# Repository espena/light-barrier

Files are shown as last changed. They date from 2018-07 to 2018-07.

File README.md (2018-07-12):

# Light barrier
Garage door light barrier. KiCad project with schematics and PCB layout. This project is shared under GNU general public license version 3, and is provided "as is", with no warranties what so ever. Use this material completely at your own risk.

## Transmitter circuit

| Component ID  | Type | Description | Value  |
| --- |:---|:---| ---:|
|  C1 | Capacitor | Radial electrolytic, 10V | 1000µF |
|  C2 | Capacitor | Monolithic Ceramic Chip |  470pF |
|  C3 | Capacitor | Monolithic Ceramic Chip |  100nF |
|  C4 | Capacitor | Monolithic Ceramic Chip |  100nF |
|  C5 | Capacitor | Monolithic Ceramic Chip |  100nF |
|  D1 | Diode | 1N4001, 50V | -  |
|  D2 | LED | Green, 5mm | -  |
|  D3 | IR-LED | TSAL 6100 | -  |
|  J1 | Terminal block | KF128 2-pin, 5 mm pitch | -  |
| JP1 | Jumper | 1x2 pin header with jumper | -  |
|  Q1 | Transistor | BC338 NPN BJT | -  |
|  R1 | Resistor | Metal film, 1% tolerance | 1kΩ |
|  R2 | Resistor | Metal film, 1% tolerance | 24kΩ |
|  R3 | Resistor | Metal film, 1% tolerance |  120kΩ |
|  R4 | Resistor | Metal film, 1% tolerance | 22kΩ |
|  R5 | Resistor | Metal film, 1% tolerance |  680kΩ |
|  R6 | Resistor | Metal film, 1% tolerance | 10kΩ |
|  R7 | Resistor | Metal film, 1% tolerance |  100kΩ |
|  R8 | Resistor | Metal film, 1% tolerance | 10Ω  |
| RV1 | Potentiometer  | Cermet 25-turn 3296W-1 | 10kΩ |
|  U1 | IC | TLC555 timer circuit | -  |
|  U2 | IC | TLC555 timer circuit | -  |

PCB layout for the transmitter is shared via
[OSH Park](https://oshpark.com/shared_projects/Knkobcg6)

## Receiver circuit

| Component ID  | Type | Description | Value  |
| --- |:---|:---| ---:|
|  C1 | Capacitor | Radial electrolytic | 47µF |
|  C2 | Capacitor | Monolithic Ceramic Chip |  100nF |
|  C3 | Capacitor | Radial electrolytic | 10µF |
|  C4 | Capacitor | Monolithic Ceramic Chip |  100nF |
|  C5 | Capacitor | Monolithic Ceramic Chip |  100nF |
|  C6 | Capacitor | Monolithic Ceramic Chip |  100nF |
|  C7 | Capacitor | Radial electrolytic, 10V | 1000µF |
|  D1 | Diode | 1N4001, 50V | -  |
|  D2 | Diode | 1N4001, 50V | -  |
|  D3 | LED | Red, 5mm | -  |
|  D4 | Diode | 1N4001, 50V | -  |
|  J1 | Terminal block | KF128 2-pin, 5 mm pitch | -  |
|  Q1 | Transistor | BC557 PNP BJT | -  |
|  Q2 | Transistor | TIP120 darlington | -  |
|  R1 | Resistor | Metal film, 1% tolerance |  6,2kΩ |
|  R2 | Resistor | Metal film, 1% tolerance | 100Ω |
|  R3 | Resistor | Metal film, 1% tolerance |  100kΩ |
|  R4 | Resistor | Metal film, 1% tolerance |  100kΩ |
|  R5 | Resistor | Metal film, 1% tolerance |  6,8kΩ |
|  R6 | Resistor | Metal film, 1% tolerance | 1kΩ |
| RV1 | Potentiometer  | Cermet 25-turn 3296W-1 |  100kΩ |
| RV2 | Potentiometer  | Cermet 25-turn 3296W-1 |  100kΩ |
|  U1 | IC | VS1838 IR receiver | -  |
|  U2 | IC | TLC555 timer circuit | -  |
|  U3 | IC | TLC555 timer circuit | -  |

PCB layout for the receiver is shared via
[OSH Park](https://oshpark.com/shared_projects/EA8wav7z)

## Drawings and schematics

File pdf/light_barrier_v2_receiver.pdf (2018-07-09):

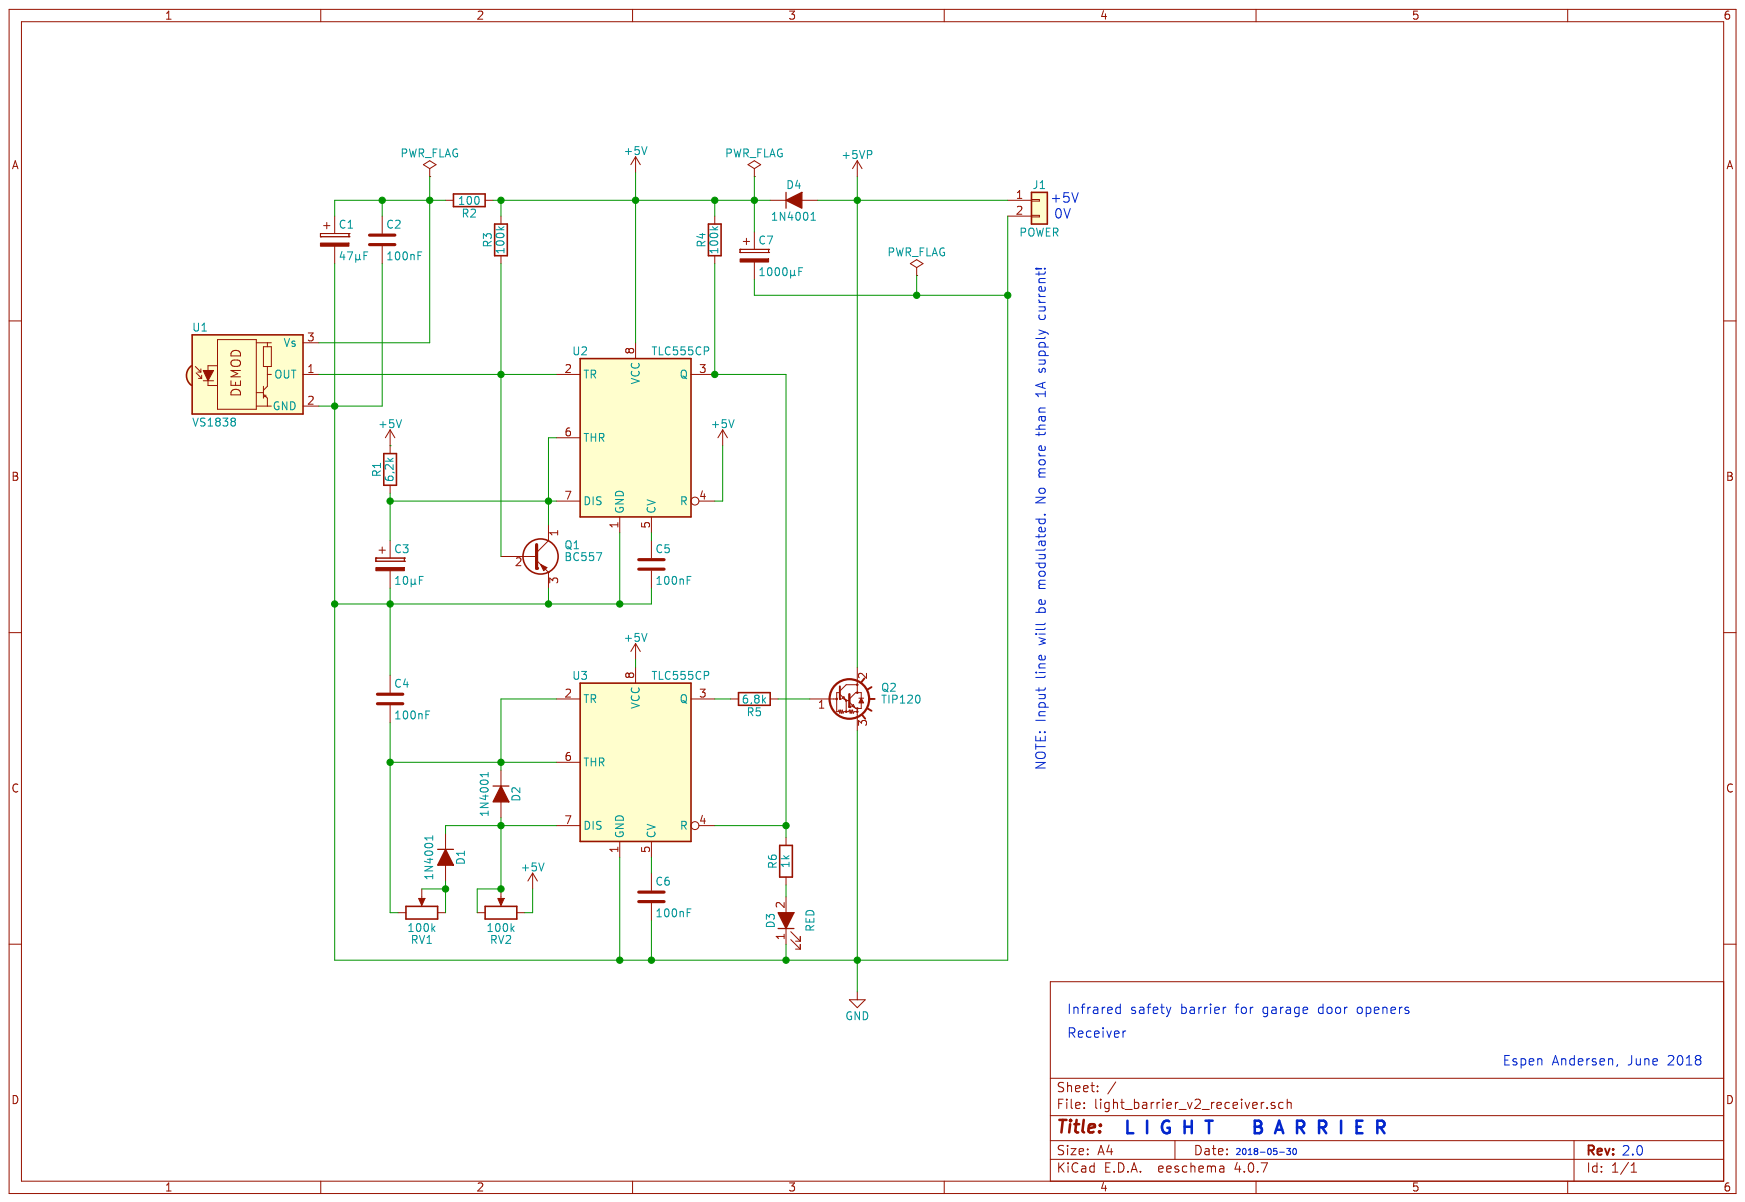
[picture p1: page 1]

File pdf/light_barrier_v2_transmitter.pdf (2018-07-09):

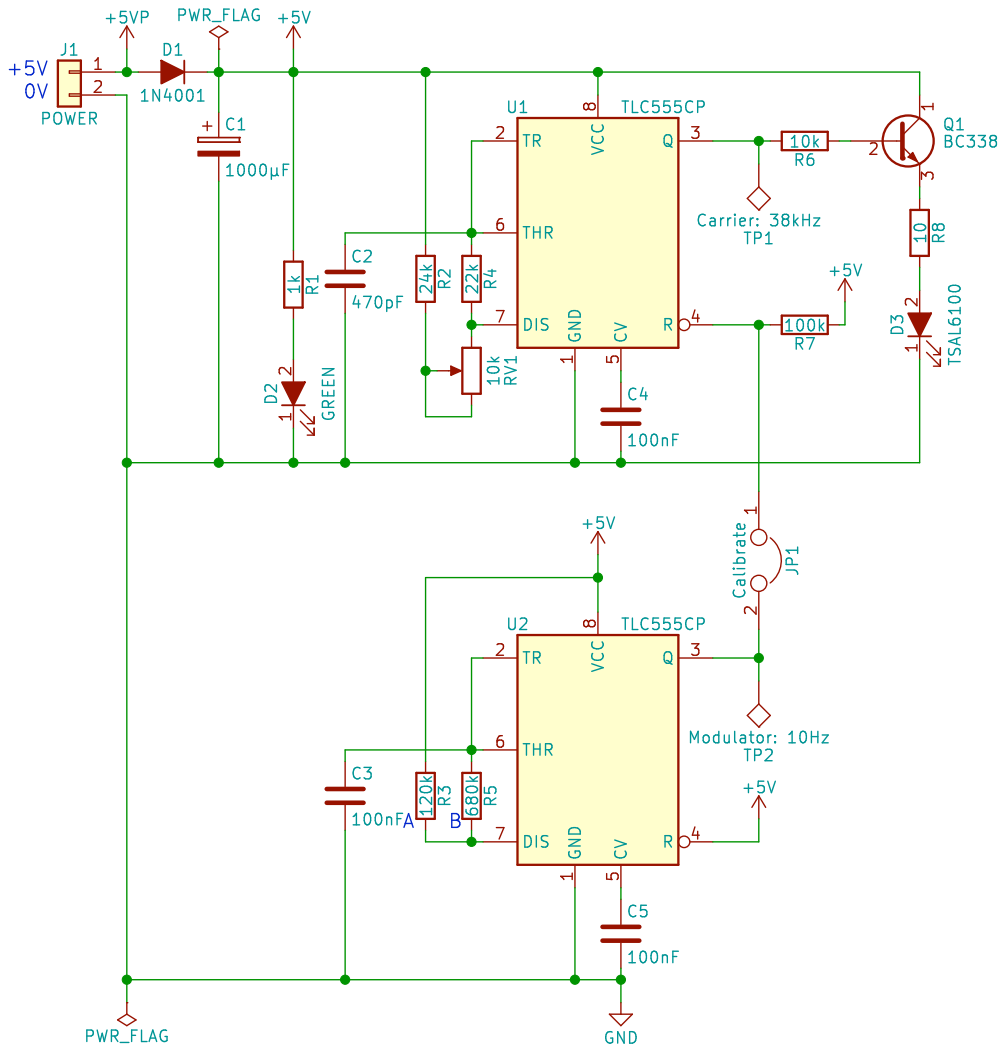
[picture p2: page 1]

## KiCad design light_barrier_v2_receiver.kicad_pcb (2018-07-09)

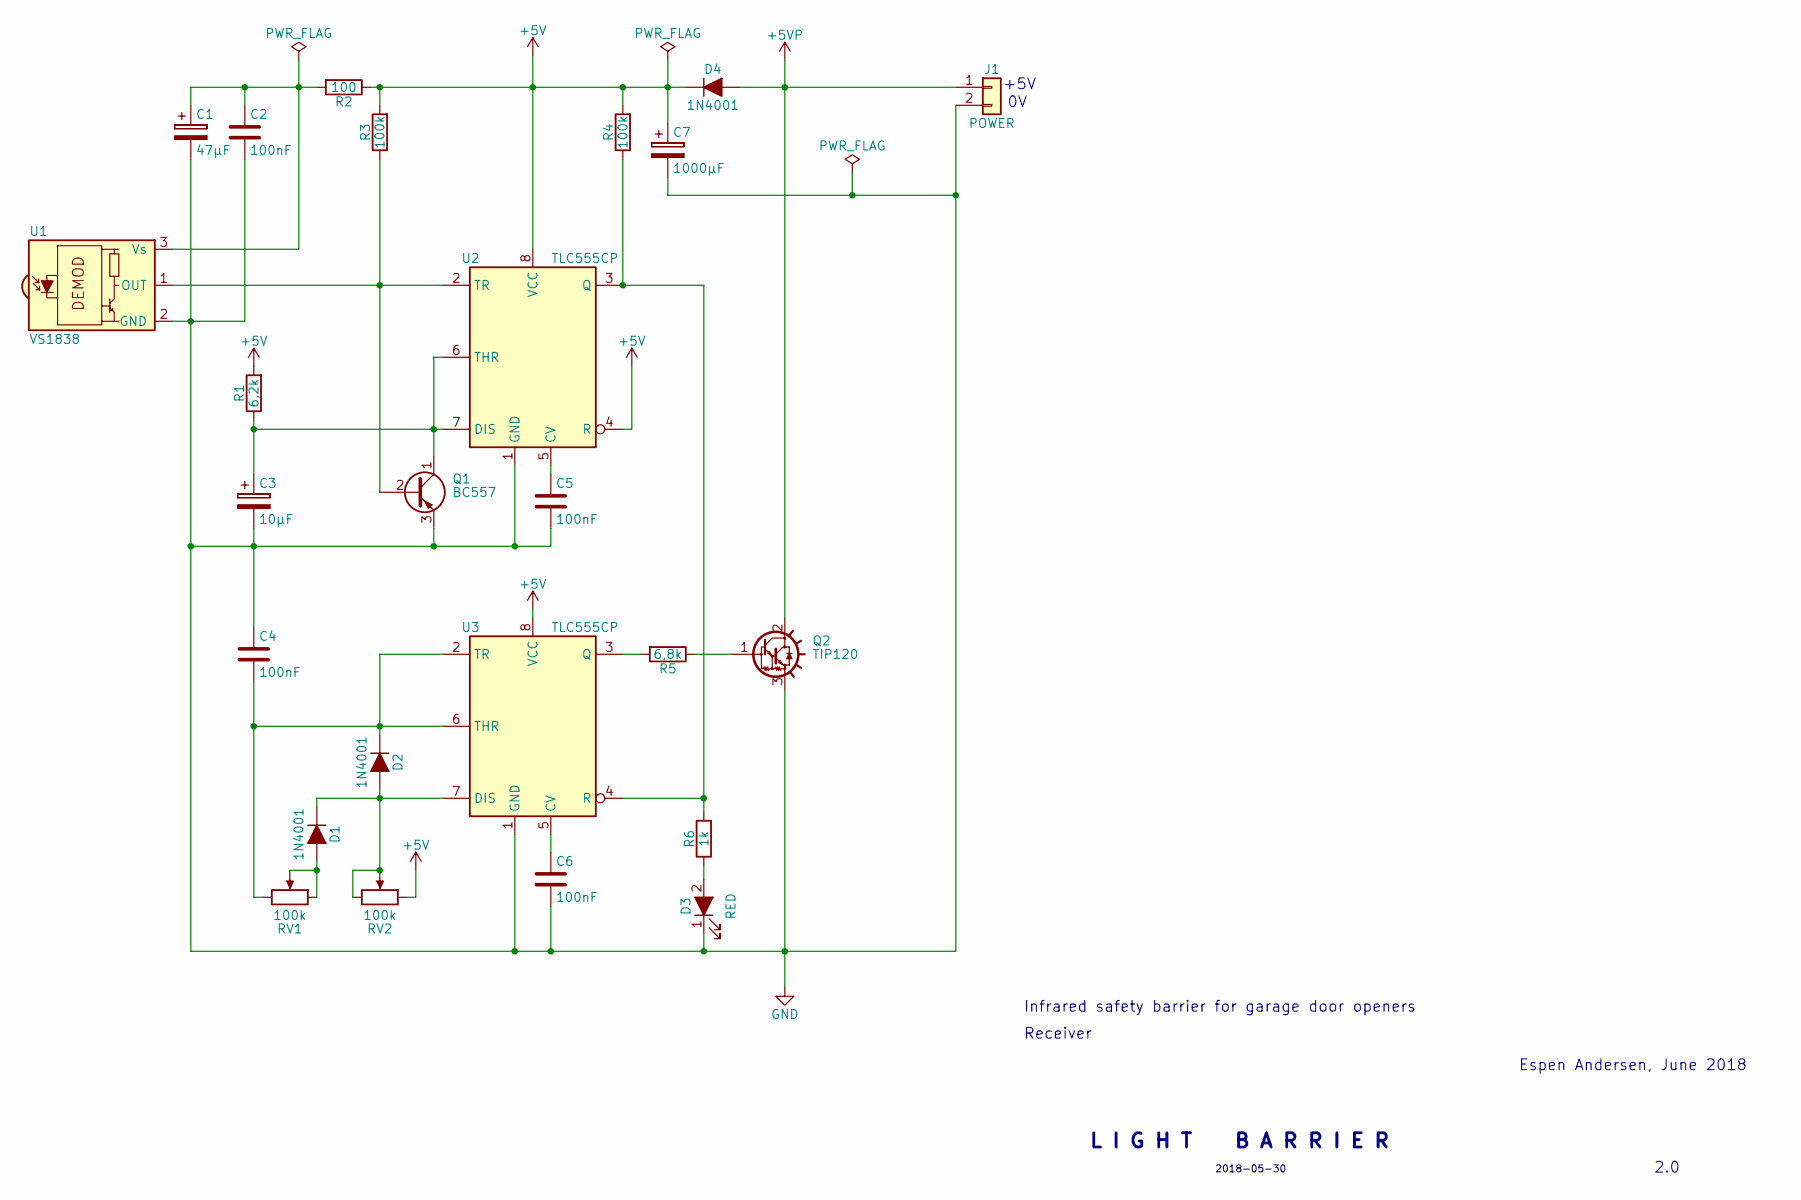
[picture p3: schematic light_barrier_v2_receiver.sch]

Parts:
C1: 47µF; CP_Radial_D4.0mm_P2.00mm
C2, C4, C5, C6: 100nF; C_Disc_D4.3mm_W1.9mm_P5.00mm
C3: 10µF; CP_Radial_D4.0mm_P2.00mm
C7: 1000µF; CP_Radial_D12.5mm_P5.00mm
D1, D2: 1N4001; D_DO-41_SOD81_P2.54mm_Vertical_KathodeUp
D3: RED; LED_D5.0mm
D4: 1N4001; D_DO-41_SOD81_P7.62mm_Horizontal
J1: POWER; TerminalBlock_Phoenix_PT-3.5mm_2pol
Q1: BC557; TO-92_Molded_Narrow_Oval
Q2: TIP120; TO-220-3_Vertical
R1: 6,2k; R_Axial_DIN0207_L6.3mm_D2.5mm_P2.54mm_Vertical
R2: 100; R_Axial_DIN0207_L6.3mm_D2.5mm_P7.62mm_Horizontal
R3, R4: 100k; R_Axial_DIN0207_L6.3mm_D2.5mm_P2.54mm_Vertical
R5: 6,8k; R_Axial_DIN0207_L6.3mm_D2.5mm_P2.54mm_Vertical
R6: 1k; R_Axial_DIN0207_L6.3mm_D2.5mm_P2.54mm_Vertical
RV1, RV2: 100k; Potentiometer_Trimmer_Bourns_3296W
U1: VS1838; IRReceiver_Vishay_MINICAST-3pin
U2, U3: TLC555CP; DIP-8_W7.62mm_LongPads

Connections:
+5V: C7.1, D4.1 (K), R1.2, R2.1, R3.2, R4.2, RV2.1, U2.4 (R), U2.8 (VCC), U3.8 (VCC)
+5VP: D4.2 (A), J1.1, Q2.2 (C)
GND: C1.2, C2.2, C3.2, C4.1, C5.2, C6.2, C7.2, D3.1 (K), J1.2, Q1.3 (E), Q2.3 (E), U1.2 (GND), U2.1 (GND), U3.1 (GND)
unnamed: C1.1, C2.1, R2.2, U1.3 (Vs)
unnamed: C3.1, Q1.1 (C), R1.1, U2.6 (THR), U2.7 (DIS)
unnamed: C4.2, D2.1 (K), RV1.3, U3.2 (TR), U3.6 (THR)
unnamed: C5.1, U2.5 (CV)
unnamed: C6.1, U3.5 (CV)
unnamed: D1.1 (K), D2.2 (A), RV2.2, RV2.3, U3.7 (DIS)
unnamed: D1.2 (A), RV1.1, RV1.2
unnamed: D3.2 (A), R6.1
unnamed: Q1.2 (B), R3.1, U1.1 (OUT), U2.2 (TR)
unnamed: Q2.1 (B), R5.1
unnamed: R4.1, R6.2, U2.3 (Q), U3.4 (R)
unnamed: R5.2, U3.3 (Q)

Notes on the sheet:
L I G H T B A R R I E R
Espen Andersen, June 2018
2018-05-30
2.0
Infrared safety barrier for garage door openers
+5V
Receiver

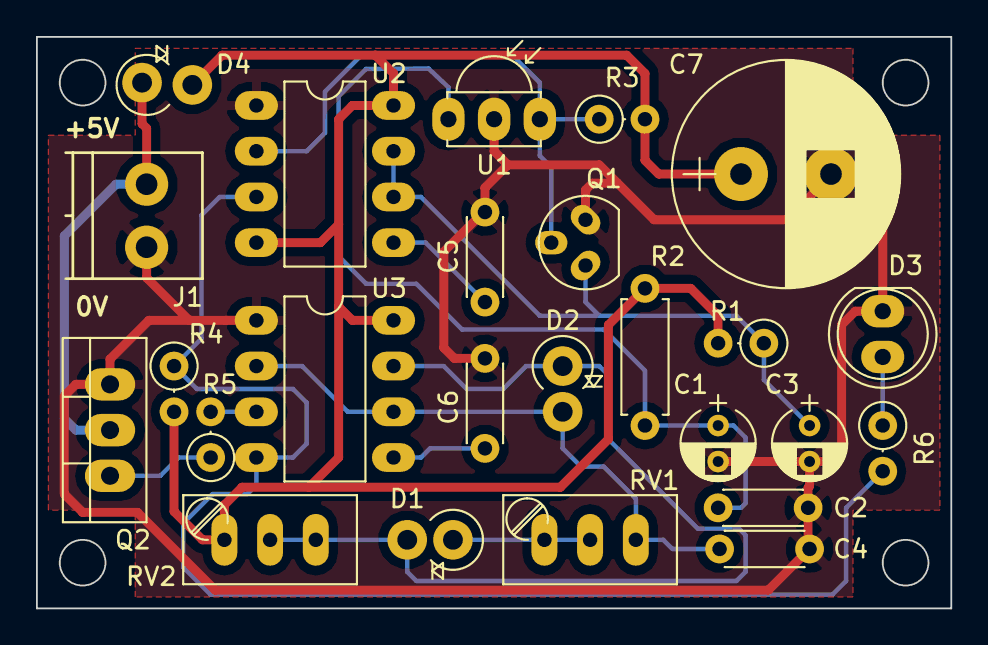
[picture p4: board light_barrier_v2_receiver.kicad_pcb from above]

Board: 2 copper layers, 50.8 x 31.8 mm, 25 parts (0 on the bottom side), 15 nets.

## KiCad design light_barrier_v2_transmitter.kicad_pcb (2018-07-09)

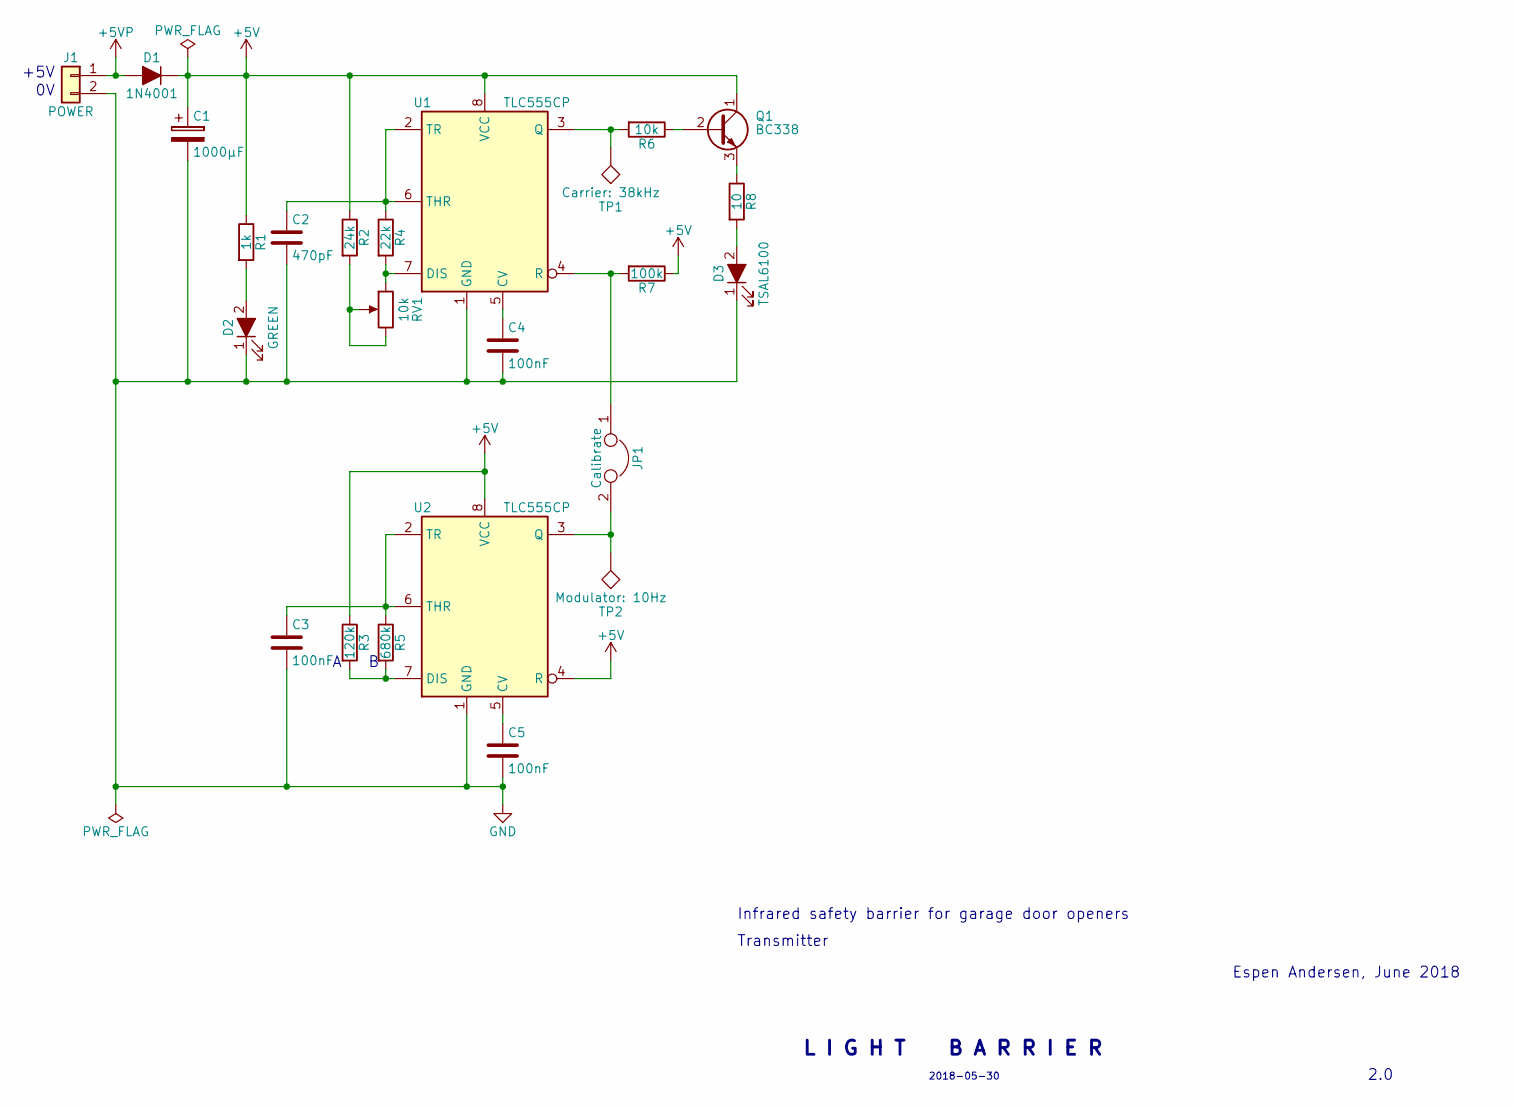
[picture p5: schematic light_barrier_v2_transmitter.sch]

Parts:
C1: 1000µF; CP_Radial_D12.5mm_P5.00mm
C2: 470pF; C_Disc_D4.3mm_W1.9mm_P5.00mm
C3, C4, C5: 100nF; C_Disc_D4.3mm_W1.9mm_P5.00mm
D1: 1N4001; D_DO-41_SOD81_P7.62mm_Horizontal
D2: GREEN; LED_D5.0mm
D3: TSAL6100; LED_D5.0mm
J1: POWER; Socket_Strip_Straight_1x02_Pitch2.54mm
JP1: Calibrate; Pin_Header_Straight_1x02_Pitch2.54mm
Q1: BC338; TO-92_Molded_Narrow
R1: 1k; R_Axial_DIN0207_L6.3mm_D2.5mm_P2.54mm_Vertical
R2: 24k; R_Axial_DIN0207_L6.3mm_D2.5mm_P2.54mm_Vertical
R3: 120k; R_Axial_DIN0207_L6.3mm_D2.5mm_P2.54mm_Vertical
R4: 22k; R_Axial_DIN0207_L6.3mm_D2.5mm_P2.54mm_Vertical
R5: 680k; R_Axial_DIN0207_L6.3mm_D2.5mm_P2.54mm_Vertical
R6: 10k; R_Axial_DIN0207_L6.3mm_D2.5mm_P2.54mm_Vertical
R7: 100k; R_Axial_DIN0207_L6.3mm_D2.5mm_P2.54mm_Vertical
R8: 10; R_Axial_DIN0207_L6.3mm_D2.5mm_P2.54mm_Vertical
RV1: 10k; Potentiometer_Trimmer_Bourns_3296W
TP1: Carrier: 38kHz; 1pin
TP2: Modulator: 10Hz; 1pin
U1, U2: TLC555CP; DIP-8_W7.62mm_LongPads

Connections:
+5V: C1.1, D1.1 (K), Q1.1 (C), R1.1, R2.1, R3.1, R7.1, U1.8 (VCC), U2.4 (R), U2.8 (VCC)
+5VP: D1.2 (A), J1.1
GND: C1.2, C2.2, C3.2, C4.2, C5.2, D2.1 (K), D3.1 (K), J1.2, U1.1 (GND), U2.1 (GND)
unnamed: C2.1, R4.1, U1.2 (TR), U1.6 (THR)
unnamed: C3.1, R5.1, U2.2 (TR), U2.6 (THR)
unnamed: C4.1, U1.5 (CV)
unnamed: C5.1, U2.5 (CV)
unnamed: D2.2 (A), R1.2
unnamed: D3.2 (A), R8.2
unnamed: JP1.1, R7.2, U1.4 (R)
unnamed: JP1.2, TP2.1, U2.3 (Q)
unnamed: Q1.2 (B), R6.1
unnamed: Q1.3 (E), R8.1
unnamed: R2.2, RV1.2, RV1.3
unnamed: R3.2, R5.2, U2.7 (DIS)
unnamed: R4.2, RV1.1, U1.7 (DIS)
unnamed: R6.2, TP1.1, U1.3 (Q)

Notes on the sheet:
L I G H T B A R R I E R
Espen Andersen, June 2018
2018-05-30
2.0
Infrared safety barrier for garage door openers
+5V
Transmitter

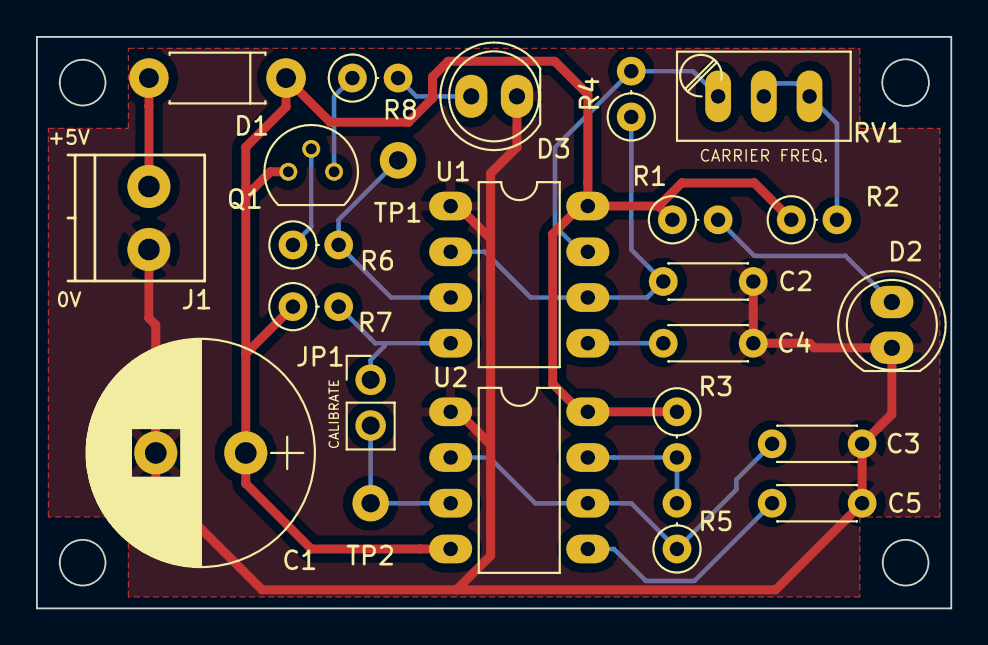
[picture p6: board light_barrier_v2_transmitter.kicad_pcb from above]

Board: 2 copper layers, 50.8 x 31.8 mm, 24 parts (0 on the bottom side), 17 nets.

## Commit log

2018-07-09 Added warning to schematics
    [light_barrier_v2_receiver.sch]
2018-07-12 Add links to shared PCB layout.
